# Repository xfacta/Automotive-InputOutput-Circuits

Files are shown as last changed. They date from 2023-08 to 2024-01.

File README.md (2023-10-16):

# Automotive-InputOutput-Circuits
Circuit diagrams used with the Arduino sketches

The Power Supply schematic includes a 5vdc Sensor regulator. This reduces the load (and heat generated) on
the Arduino on-board linear regulator, and also allows more effective input protection
by diverting high voltages to the 5vdc Sensor reg via schotttky diodes, where the over-voltage can be absorbed
by a 5.6v 5watt zener, filter capacitors and schottky diode.
The LM2940CT-5 regulator is suitable for automotive applications and handles reverse voltages and load dumps,
even though those events are unlikely to happen to that regulator considering where it is on the circuit.

The Arduinos are powered via their input barrels (soldered wires) from a "Arduino" 2.5A adjustable switching
supply set to 10vdc. This means the protection diode and input caps are retained for isolation of
each Arduino, even though it also means the onboard linear regulator (heat generator) is also used.
Otherwise the Vin pin could be used but reverse voltage protection diode wouldnt be inline. 
Other options would require physical modification of the board.

https://www.jaycar.com.au/arduino-compatible-dc-voltage-regulator-module/p/XC4514

General supply voltage protection includes:
- PTC resettable fuse
- TVS diode
- High voltage polyester caps
- Reverse voltage protection diode
- Tranzorb transient protection zener diode
- Low ESR electrolytic caps
- Some capacitors are specified as Tantalum for the their Low ESR performance

The Tachometer Arduino outputs high RPM serial data to the Fuel/Temp/Volts Arduino, where a NeoPixel strip is used
as a shift light. The last LED on the strip is used to indicate various statuses.

Arduino analog and digital inputs are protected by schottky diodes or transorb/zeners as appropriate. Where inverters or buffers are used
they have inbuilt protection diodes and only an external resistor is used. Most of the digital inputs
are debounced in hardware via the schmitt trigger inverters and buffers, with basic noise filtering.

An Op Amp is used to get a more usable voltage range from the fuel level sensor, since the standard Datsun fuel sender
only has an 8ohm to 80ohm range.

There is facilty to use a DS18B20 one-wire temperature sensor, or there's calibration values in the
sketches for Nissan SR20 or standard NTC resistor temperature sensors.

**Light inputs:**
- Parkers and Low beam are active high
- High beam is active low, inverted by a ~~schmitt trigger~~ opto coupler placement to active high

**Sounds**
Each main Arduino (Fuel/Temp / Tacho / Speedo) outputs a warning signal and/or Oil Pressure warning signal. These are actioned
by a Leonardo Tiny and small amplifier. These releives the main Arduinos from making sounds and any related blocking delays.

**Pins from sketches:**
Not all pins are used on every Arduino.

Pin definitions for digital inputs
- Oil_Press_Pin = 0;              // Oil pressure digital input pin
- Parker_Light_Pin = 1;           // Parker lights digital input pin
- Low_Beam_Pin = 2;  // Low beam digital input pin
- High_Beam_Pin = 3;              // High beam digital input pin
- Pbrake_Input_Pin = 4;           // Park brake input pin
- VSS_Input_Pin = 5;              // Speed frequency input pin
- RPM_Input_Pin = 6;  // RPM frequency input pin
- ~~RPM_PWM_In_Pin = 6;             // Input PWM signal representing RPM~~
- Button_Pin = 7;  // Button momentary input

Pin definitions for analog inputs
- Temp_Pin = A0;                  // Temperature analog input pin - not used with OneWire sensor
- Fuel_Pin = A1;                  // Fuel level analog input pin
- Batt_Volt_Pin = A2;             // Voltage analog input pin
- Alternator_Pin = A3;            // Alternator indicator analog input pin

Pin definitions for outputs
- ~~RPM_PWM_Out_Pin = 10;            // Output of RPM as a PWM signal for shift light~~
- LED_Pin = 10;                   // NeoPixel LED pin
- Warning_Pin = 11;               // Link to external Leonardo for general warning sounds
- OP_Warning_Pin = 12;            // Link to external Leonardo for oil pressure warning sound
- Relay_Pin = 13;                 // Relay for fan control

- ONE_WIRE_BUS 14                // Specify the OneWire bus pin

DS18B20 one-wire pullup resistor guide
```
Length        5.0 Volt  3.3 Volt
10cm (4")      10K0      6K8
20cm (8")      8K2       4K7
50cm (20")      4K7      3K3
100cm (3'4")    3K3      2K2
200cm (6'8")    2K2      1K0
```

Serial2 pins used on the Mega2560s for RPM shiftlight comms
pins 17(RX), 16(TX)

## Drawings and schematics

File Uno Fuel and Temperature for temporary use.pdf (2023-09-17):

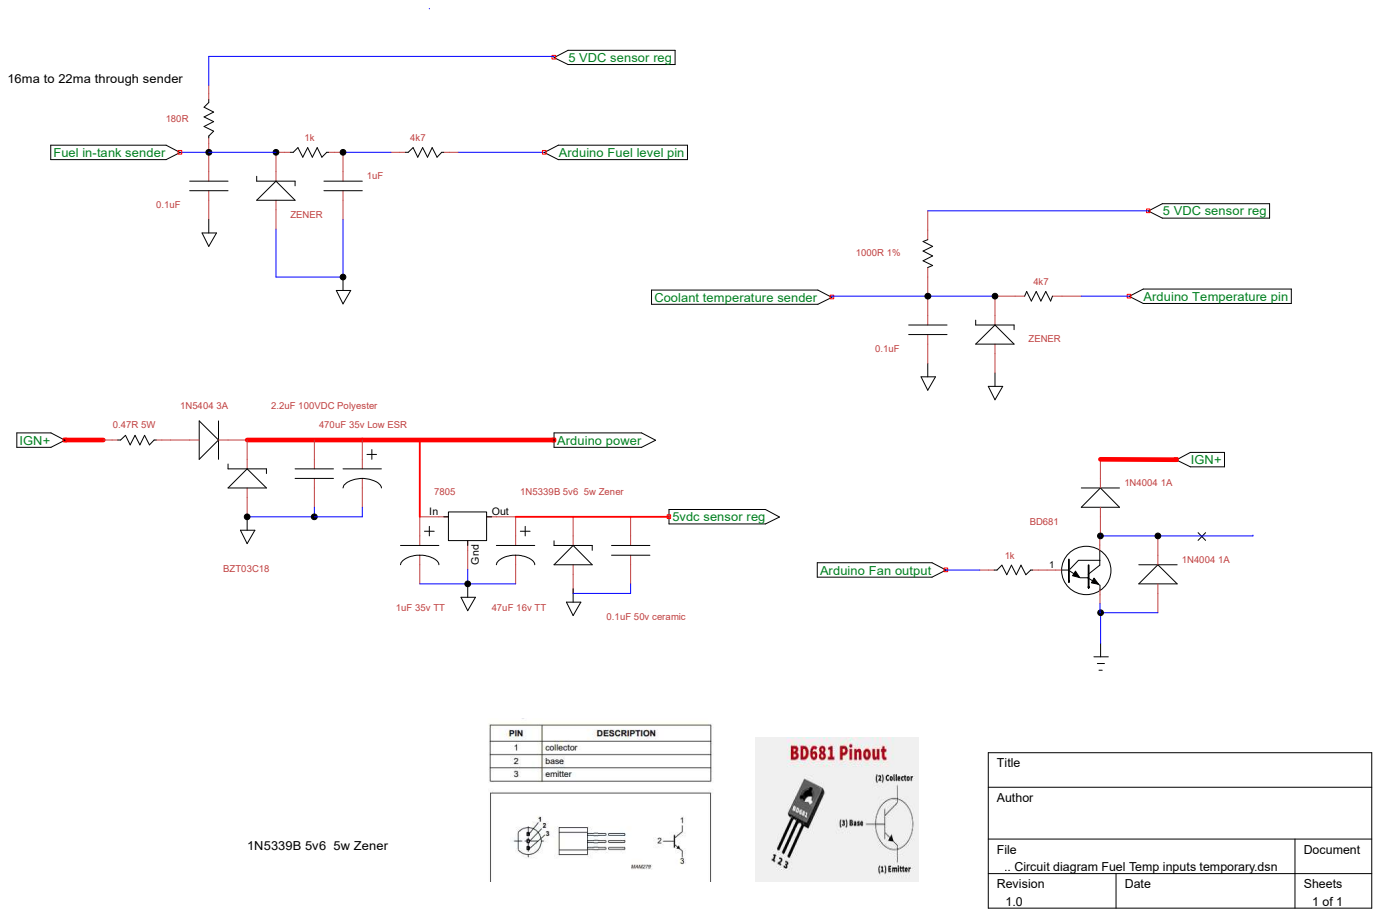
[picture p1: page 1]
Arduino Fuel level pin; ZENER; 1N5339B 5v6 5w Zener; BZT03C18; 2.2uF 100VDC Polyester; IGN+; Arduino power; 1k Arduino Fan output; 47uF 16v TT Gnd; Out; 470uF 35v Low ESR; 5vdc sensor reg; 0.1uF 50v ceramic; Title; Author

5 VDC sensor reg

1uF 16ma to 22ma through sender

Fuel in-tank sender

Coolant temperature sender

Arduino Temperature pin

File ... Circuit diagram Fuel Temp inputs temporary.dsn | Document

Revision 1.0 1 of 1 | Date | Sheets

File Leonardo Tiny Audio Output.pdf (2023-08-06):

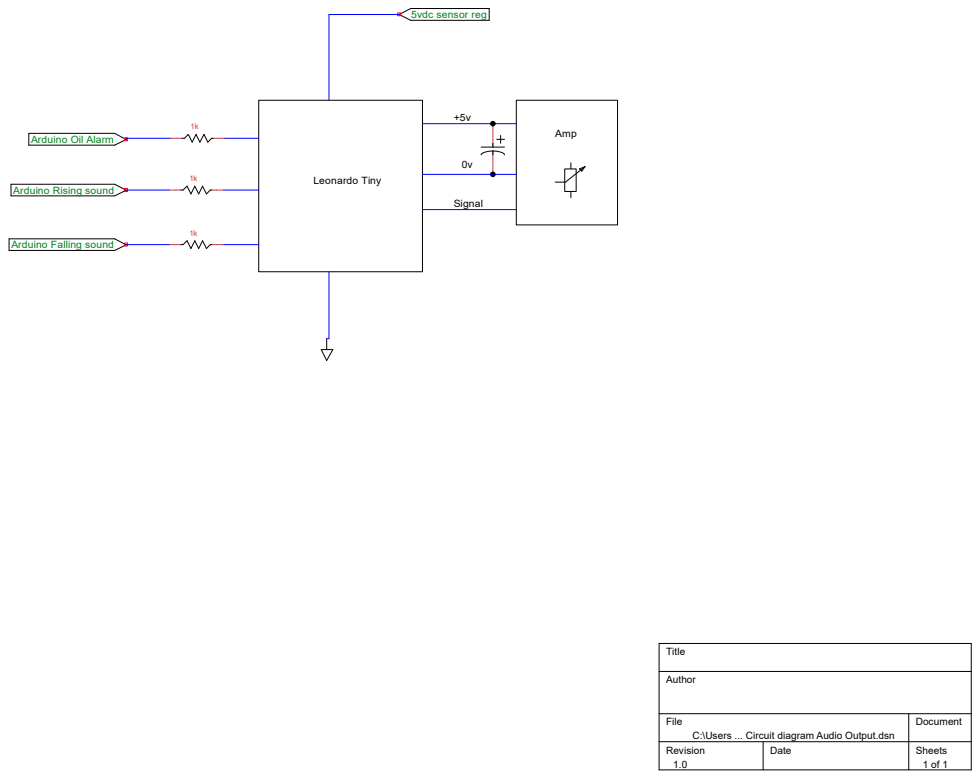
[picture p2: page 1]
5vdc sensor reg; Amp; Leonardo Tiny; Signal; Title; Author

Arduino Oil Alarm

1k Arduino Rising sound

1k Arduino Falling sound

File C:\Users ... Circuit diagram Audio Output.dsn | Document

Revision 1.0 1 of 1 | Date | Sheets

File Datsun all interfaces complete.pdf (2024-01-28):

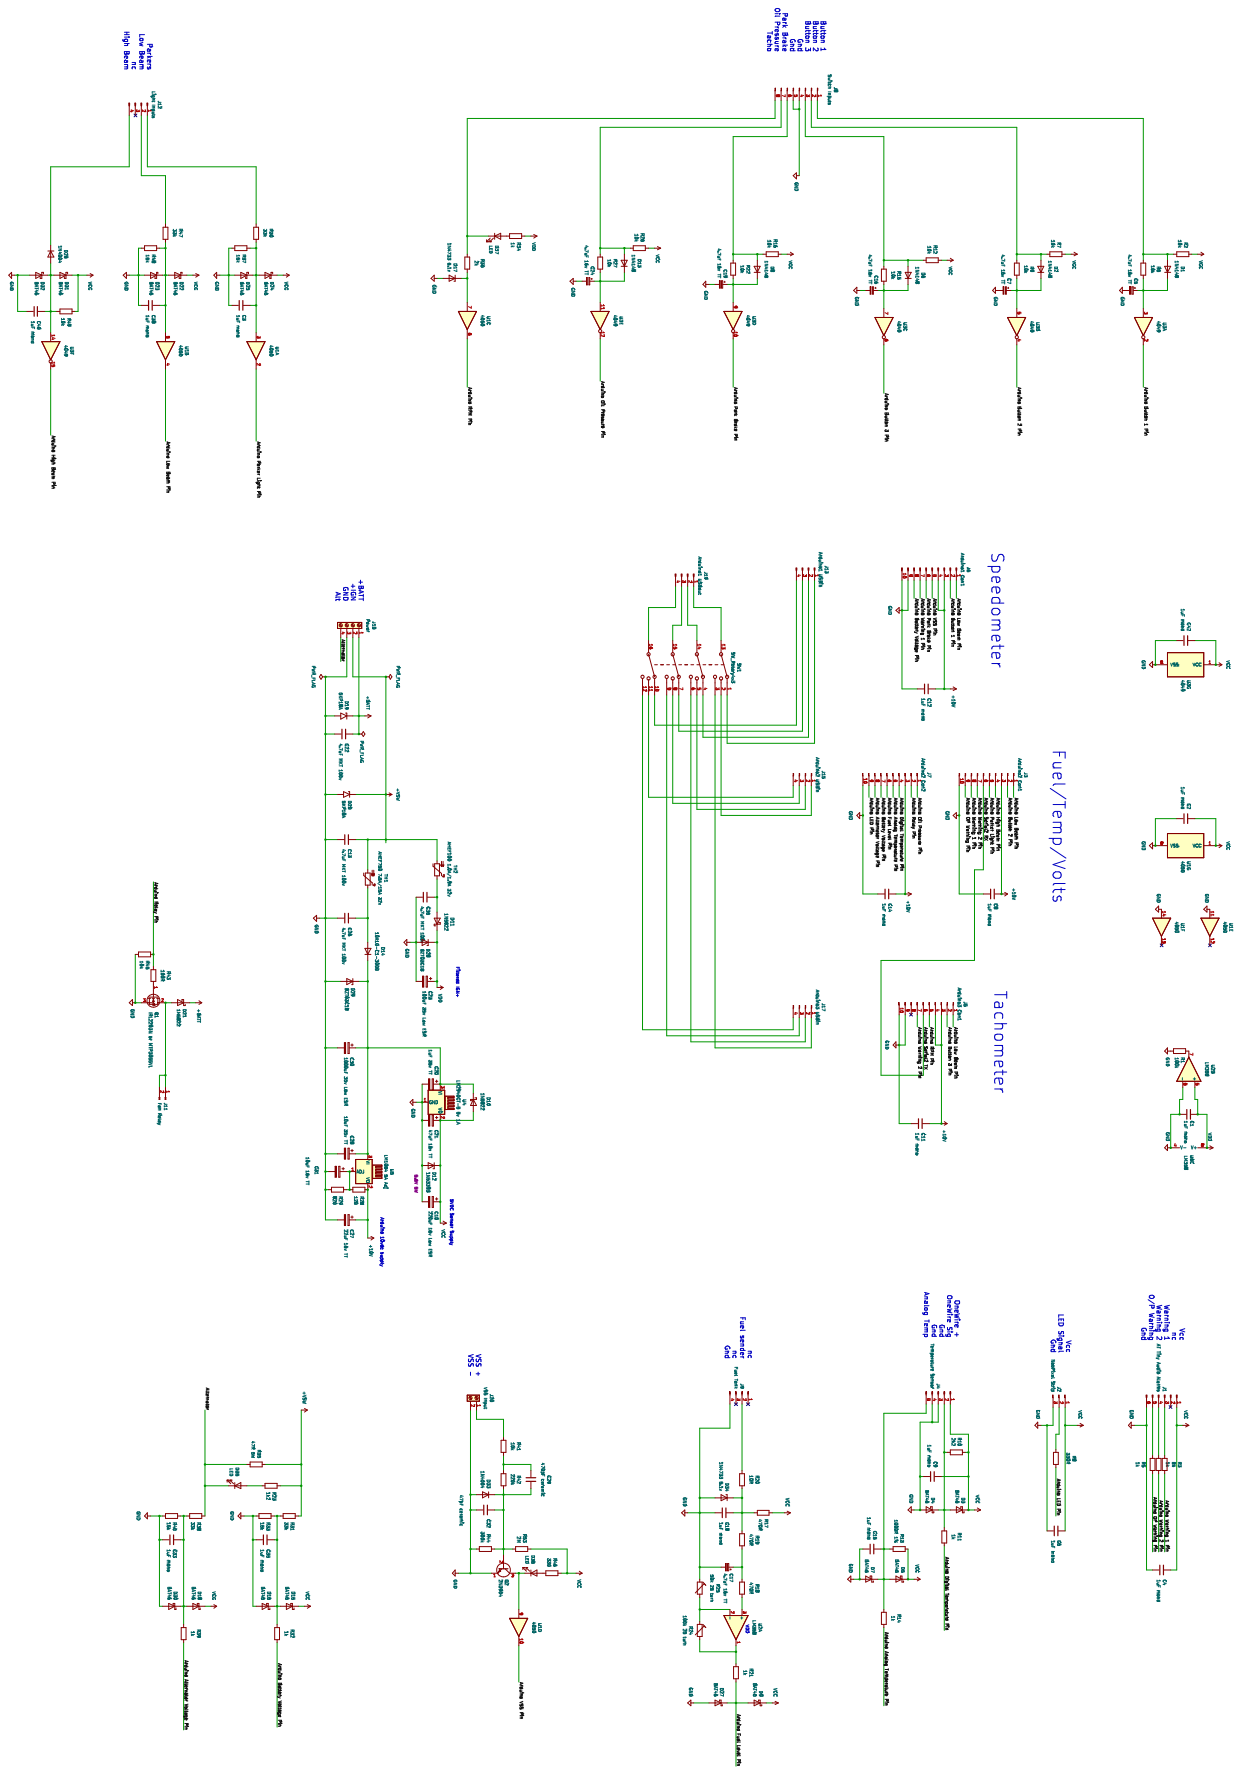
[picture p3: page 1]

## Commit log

2023-08-06 Added files
    PDFs of circuit diagrams
2023-08-06 Update Automotive Arduino Power Supply.pdf
2023-09-02 Update Automotive Arduino Power Supply.pdf
    Removed power good circuit, not needed
2023-09-04 Opto coupler updates
    Updated to a different opto coupler and suitable resistor values
2023-09-04 Update Automotive Arduino Fuel and Temperature Inputs.pdf
2023-09-17 Update Automotive Arduino Fan Relay Driver.pdf
2023-09-17 Updated
    Updated high beam detection
    Updated temporary circuit
2023-10-16 Added kicad files
    Uodated circuit diagrams, in kicad
    [Datsun Gauges Audio Output.kicad_sch, Datsun Gauges Button Inputs.kicad_sch, Datsun Gauges Fan Relay Driver.kicad_sch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]
2023-10-16 Updated kicad diagrams
    Updated kicad diagrams
    [Datsun Gauges Button Inputs.kicad_sch, Datsun Gauges Fan Relay Driver.kicad_sch, Datsun Gauges Fuel Temp Inputs.kicad_sch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]
2023-10-20 Fixes
    Changed some switch debouncing
    [Datsun Gauges Button Inputs.kicad_sch, Datsun Gauges Oil Tacho inputs.kicad_sch]
2024-01-28 Combined all circuits
    Combined all circuits
    [Datsun Gauges Audio Output.kicad_sch, Datsun Gauges Button Inputs.kicad_sch, Datsun Gauges Complete.kicad_sch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]
